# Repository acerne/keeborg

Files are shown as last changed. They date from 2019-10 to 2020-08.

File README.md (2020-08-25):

# Keeborg
*Oh look, another split keyboard*	

## Idea
Keeborg is a sandbox prototype inspired from split keyboards like ErgoDox, Iris, Sol2 and many others, that give your tumbs more to do besides spacebar mashing. Taking a level further with thoughts of rotary encoders, joysticks, trackballs and other input devices, rarely seen o na keyboard.

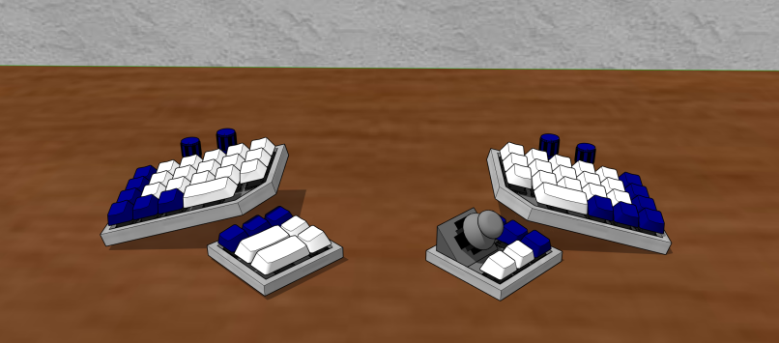
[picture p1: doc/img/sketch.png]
sketch
  

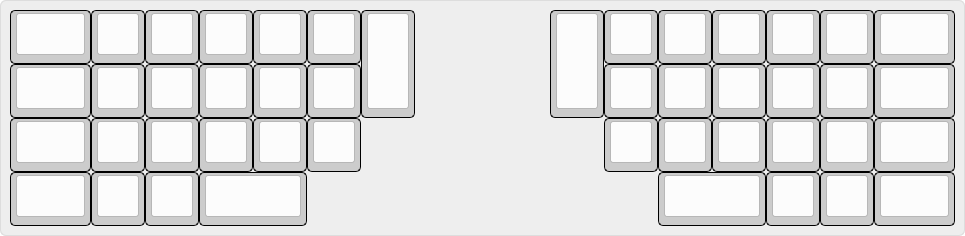
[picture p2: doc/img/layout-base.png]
layout
  

## Status
Designed a simple one-sided reversible PCB, made a fully functional thumb-less left-hand cluster. Had header connectors for some modular miny-pcb addons. After some testing decided it's not as expected and abandoned the project. 

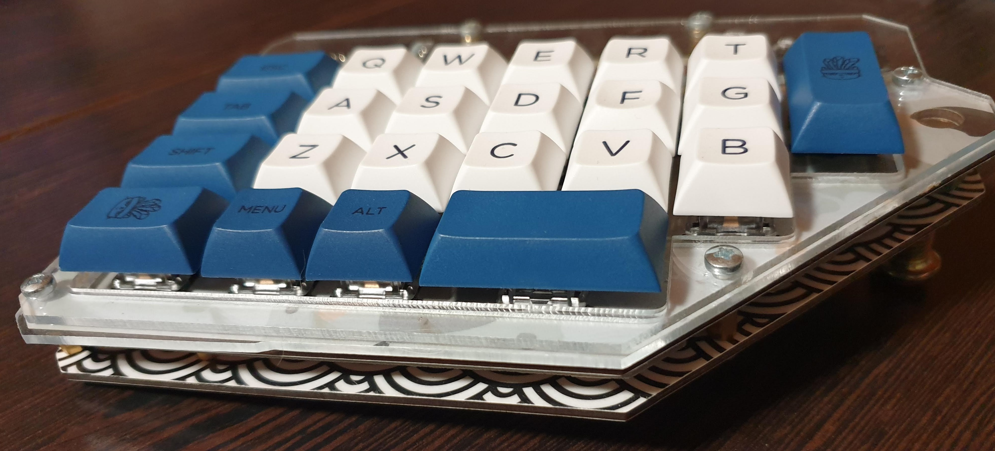
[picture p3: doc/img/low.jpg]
low
  

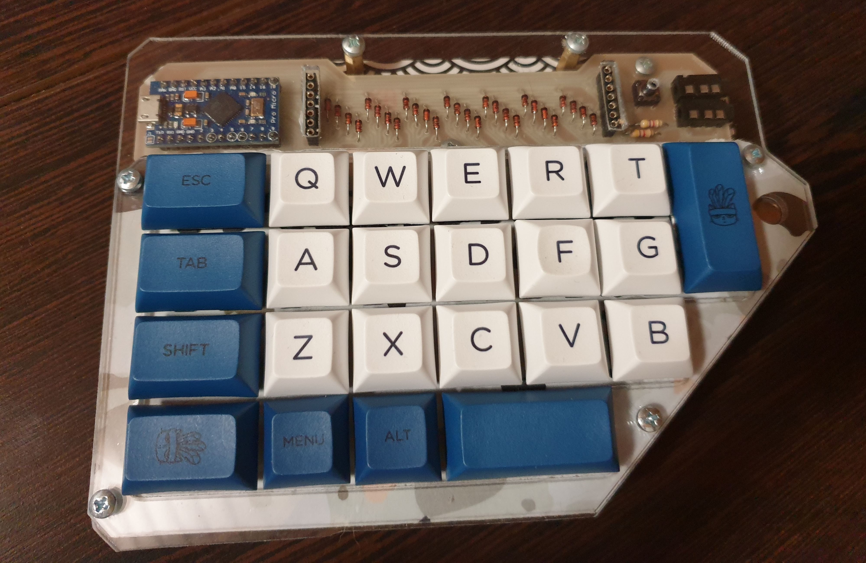
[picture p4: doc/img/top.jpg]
top


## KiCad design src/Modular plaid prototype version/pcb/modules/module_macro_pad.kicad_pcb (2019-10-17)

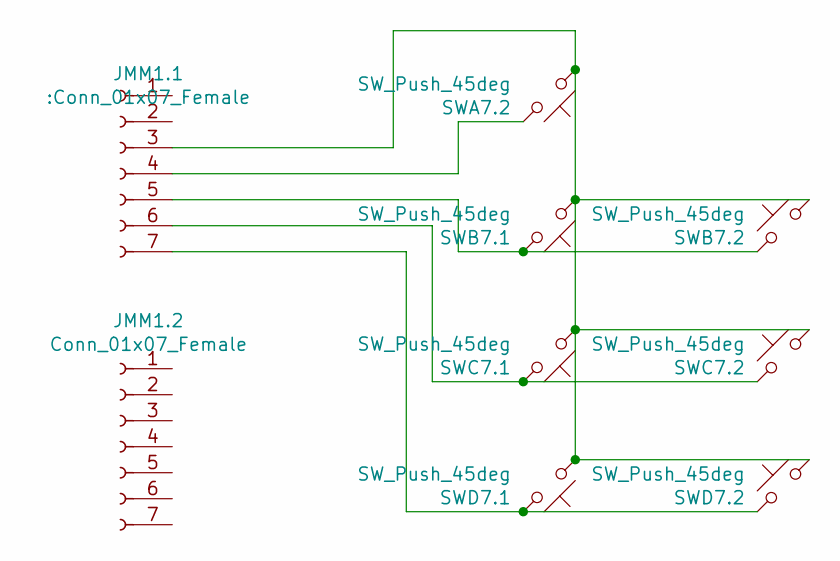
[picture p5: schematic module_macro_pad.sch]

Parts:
JMM1.1: :Conn_01x07_Female; PinHeader_1x07_P2.54mm_Vertical
JMM1.2: Conn_01x07_Female; PinHeader_1x07_P2.54mm_Vertical
SWA7.2: SW_Push_45deg; Hybrid_Plate_100H_Dual_hole-nosilk
SWB7.1, SWB7.2: SW_Push_45deg; Hybrid_Plate_100H_Dual_hole-nosilk
SWC7.1, SWC7.2: SW_Push_45deg; Hybrid_Plate_100H_Dual_hole-nosilk
SWD7.1, SWD7.2: SW_Push_45deg; Hybrid_Plate_100H_Dual_hole-nosilk

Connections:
unnamed: JMM1.1.3, SWA7.2.1, SWB7.1.1, SWB7.2.2, SWC7.1.1, SWC7.2.2, SWD7.1.1, SWD7.2.2
unnamed: JMM1.1.4, SWA7.2.2
unnamed: JMM1.1.5, SWB7.1.2, SWB7.2.1
unnamed: JMM1.1.6, SWC7.1.2, SWC7.2.1
unnamed: JMM1.1.7, SWD7.1.2, SWD7.2.1

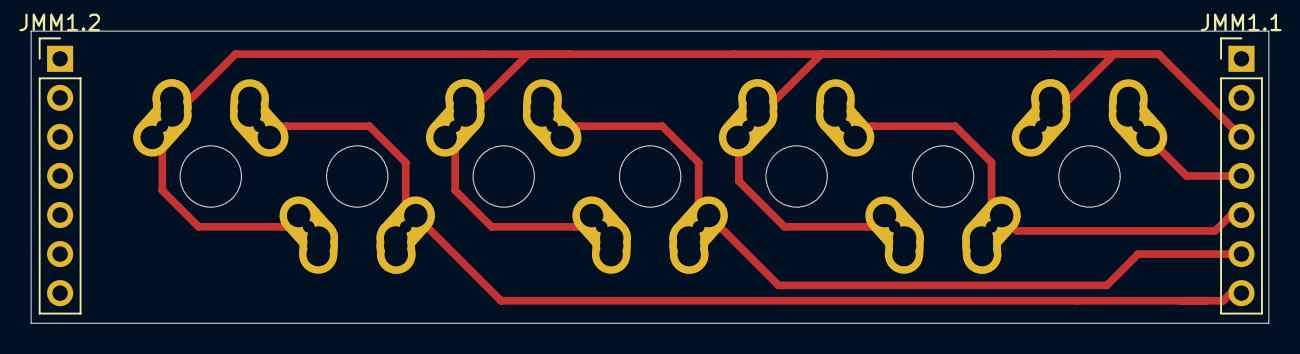
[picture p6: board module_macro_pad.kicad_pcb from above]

Board: 2 copper layers, 80.5 x 19.0 mm, 9 parts (0 on the bottom side), 5 nets.

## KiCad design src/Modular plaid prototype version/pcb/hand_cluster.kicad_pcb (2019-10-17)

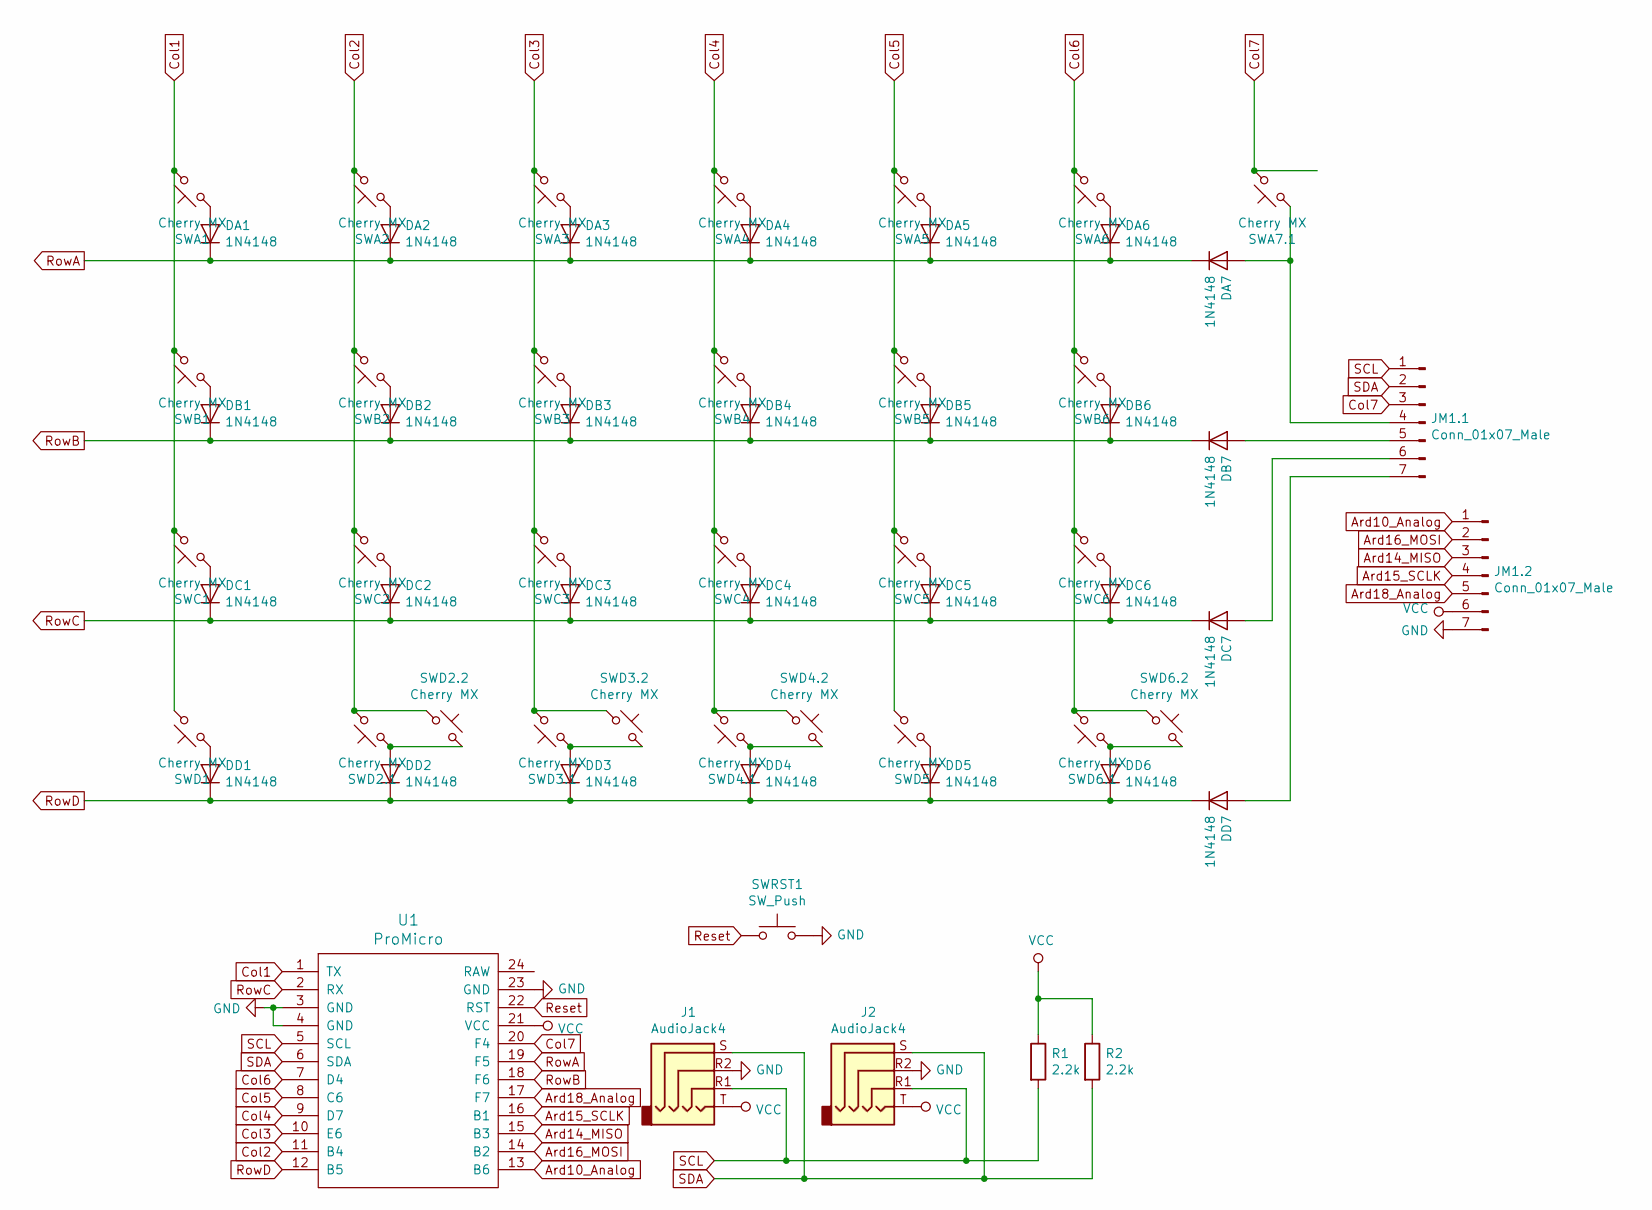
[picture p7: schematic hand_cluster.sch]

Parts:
DA1, DA2, DA3, DA4, DA5, DA6, DA7: 1N4148; D_DO-35_SOD27_P7.62mm_Horizontal
DB1, DB2, DB3, DB4, DB5, DB6, DB7: 1N4148; D_DO-35_SOD27_P7.62mm_Horizontal
DC1, DC2, DC3, DC4, DC5, DC6, DC7: 1N4148; D_DO-35_SOD27_P7.62mm_Horizontal
DD1, DD2, DD3, DD4, DD5, DD6, DD7: 1N4148; D_DO-35_SOD27_P7.62mm_Horizontal
J1, J2: AudioJack4; TRRS-PJ-320A-dual-labeled
JM1.1, JM1.2: Conn_01x07_Male; PinHeader_1x07_P2.54mm_Vertical
R1, R2: 2.2k; Resistor
SWA1: Cherry MX; Hybrid_Plate_150H_Dual_hole-nosilk
SWA2, SWA3, SWA4, SWA5, SWA6, SWA7.1: Cherry MX; Hybrid_Plate_100H_Dual_hole-nosilk
SWB1: Cherry MX; Hybrid_Plate_150H_Dual_hole-nosilk
SWB2, SWB3, SWB4, SWB5, SWB6: Cherry MX; Hybrid_Plate_100H_Dual_hole-nosilk
SWC1: Cherry MX; Hybrid_Plate_150H_Dual_hole-nosilk
SWC2, SWC3, SWC4, SWC5, SWC6: Cherry MX; Hybrid_Plate_100H_Dual_hole-nosilk
SWD1: Cherry MX; Hybrid_Plate_150H_Dual_hole-nosilk
SWD2.1, SWD2.2, SWD3.1, SWD3.2, SWD4.1, SWD4.2, SWD5, SWD6.1, SWD6.2: Cherry MX; Hybrid_Plate_100H_Dual_hole-nosilk
SWRST1: SW_Push; SW_PUSH_6mm
U1: ProMicro; ArduinoProMicro

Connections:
Ard10_Analog: JM1.2.1, U1.13 (B6)
Ard14_MISO: JM1.2.3, U1.15 (B3)
Ard15_SCLK: JM1.2.4, U1.16 (B1)
Ard16_MOSI: JM1.2.2, U1.14 (B2)
Ard18_Analog: JM1.2.5, U1.17 (F7)
Col1: SWA1.2, SWB1.2, SWC1.2, SWD1.2, U1.1 (TX)
Col2: SWA2.2, SWB2.2, SWC2.2, SWD2.1.2, SWD2.2.1, U1.11 (B4)
Col3: SWA3.2, SWB3.2, SWC3.2, SWD3.1.2, SWD3.2.1, U1.10 (E6)
Col4: SWA4.2, SWB4.2, SWC4.2, SWD4.1.2, SWD4.2.1, U1.9 (D7)
Col5: SWA5.2, SWB5.2, SWC5.2, SWD5.2, U1.8 (C6)
Col6: SWA6.2, SWB6.2, SWC6.2, SWD6.1.2, SWD6.2.1, U1.7 (D4)
Col7: JM1.1.3, SWA7.1.2, U1.20 (F4)
GND: J1.R2, J2.R2, JM1.2.7, SWRST1.2, U1.3 (GND), U1.4 (GND), U1.23 (GND)
unnamed: DA1.2 (A), SWA1.1
unnamed: DA2.2 (A), SWA2.1
unnamed: DA3.2 (A), SWA3.1
unnamed: DA4.2 (A), SWA4.1
unnamed: DA5.2 (A), SWA5.1
unnamed: DA6.2 (A), SWA6.1
unnamed: DA7.2 (A), JM1.1.4, SWA7.1.1
unnamed: DB1.2 (A), SWB1.1
unnamed: DB2.2 (A), SWB2.1
unnamed: DB3.2 (A), SWB3.1
unnamed: DB4.2 (A), SWB4.1
unnamed: DB5.2 (A), SWB5.1
unnamed: DB6.2 (A), SWB6.1
unnamed: DB7.2 (A), JM1.1.5
unnamed: DC1.2 (A), SWC1.1
unnamed: DC2.2 (A), SWC2.1
unnamed: DC3.2 (A), SWC3.1
unnamed: DC4.2 (A), SWC4.1
unnamed: DC5.2 (A), SWC5.1
unnamed: DC6.2 (A), SWC6.1
unnamed: DC7.2 (A), JM1.1.6
unnamed: DD1.2 (A), SWD1.1
unnamed: DD2.2 (A), SWD2.1.1, SWD2.2.2
unnamed: DD3.2 (A), SWD3.1.1, SWD3.2.2
unnamed: DD4.2 (A), SWD4.1.1, SWD4.2.2
unnamed: DD5.2 (A), SWD5.1
unnamed: DD6.2 (A), SWD6.1.1, SWD6.2.2
unnamed: DD7.2 (A), JM1.1.7
Reset: SWRST1.1, U1.22 (RST)
RowA: DA1.1 (K), DA2.1 (K), DA3.1 (K), DA4.1 (K), DA5.1 (K), DA6.1 (K), DA7.1 (K), U1.19 (F5)
RowB: DB1.1 (K), DB2.1 (K), DB3.1 (K), DB4.1 (K), DB5.1 (K), DB6.1 (K), DB7.1 (K), U1.18 (F6)
RowC: DC1.1 (K), DC2.1 (K), DC3.1 (K), DC4.1 (K), DC5.1 (K), DC6.1 (K), DC7.1 (K), U1.2 (RX)
RowD: DD1.1 (K), DD2.1 (K), DD3.1 (K), DD4.1 (K), DD5.1 (K), DD6.1 (K), DD7.1 (K), U1.12 (B5)
SCL: J1.R1, J2.R1, JM1.1.1, R1.2, U1.5 (SCL)
SDA: J1.S, J2.S, JM1.1.2, R2.2, U1.6 (SDA)
VCC: J1.T, J2.T, JM1.2.6, R1.1, R2.1, U1.21 (VCC)

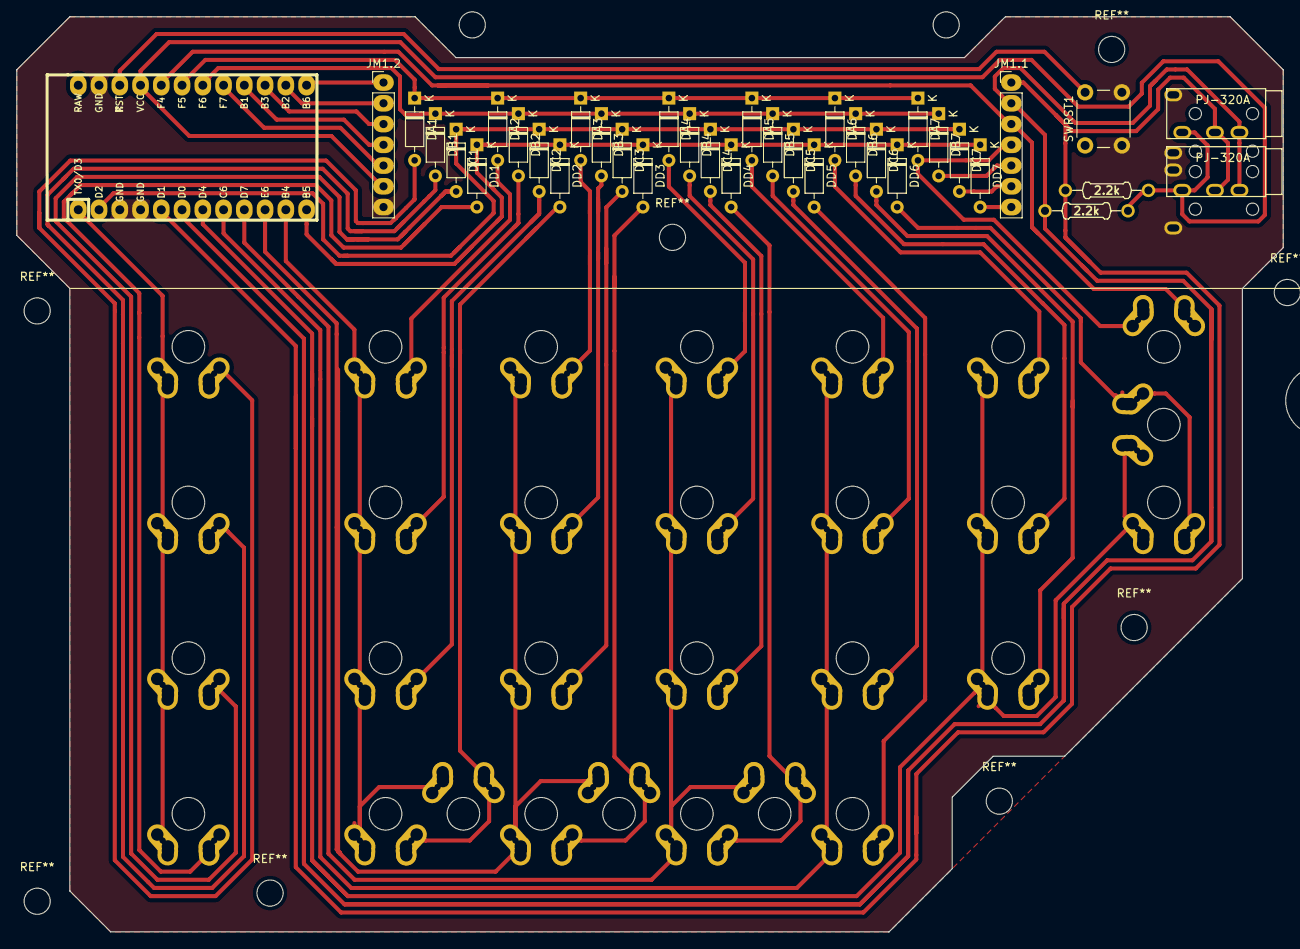
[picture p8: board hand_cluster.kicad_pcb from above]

Board: 2 copper layers, 155.0 x 112.0 mm, 65 parts (0 on the bottom side), 49 nets.

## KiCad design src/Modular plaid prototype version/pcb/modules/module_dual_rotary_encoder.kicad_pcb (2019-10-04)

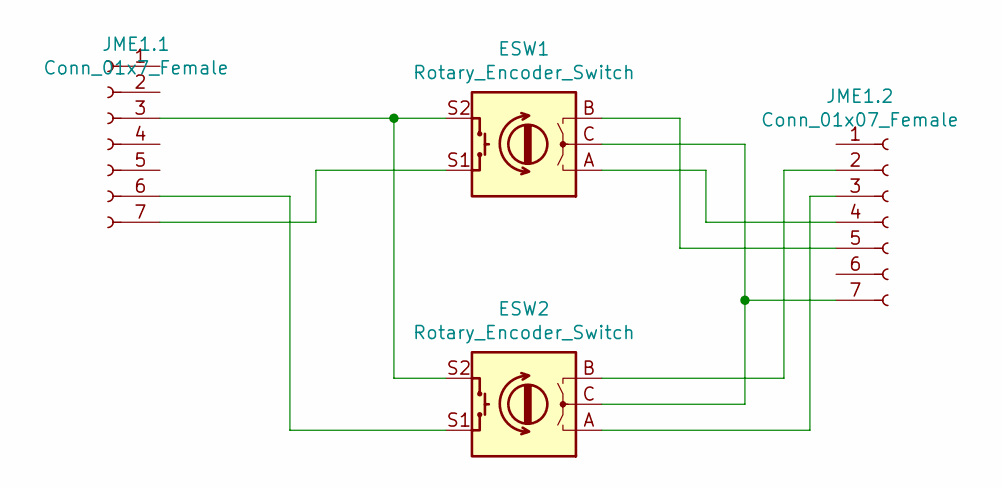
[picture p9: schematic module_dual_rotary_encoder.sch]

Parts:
ESW1, ESW2: Rotary_Encoder_Switch; RotaryEncoder_EC11
JME1.1: Conn_01x7_Female; PinHeader_1x07_P2.54mm_Vertical
JME1.2: Conn_01x07_Female; PinHeader_1x07_P2.54mm_Vertical

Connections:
unnamed: ESW1.A, JME1.2.4
unnamed: ESW1.B, JME1.2.5
unnamed: ESW1.C, ESW2.C, JME1.2.7
unnamed: ESW1.S1, JME1.1.7
unnamed: ESW1.S2, ESW2.S2, JME1.1.3
unnamed: ESW2.A, JME1.2.3
unnamed: ESW2.B, JME1.2.2
unnamed: ESW2.S1, JME1.1.6

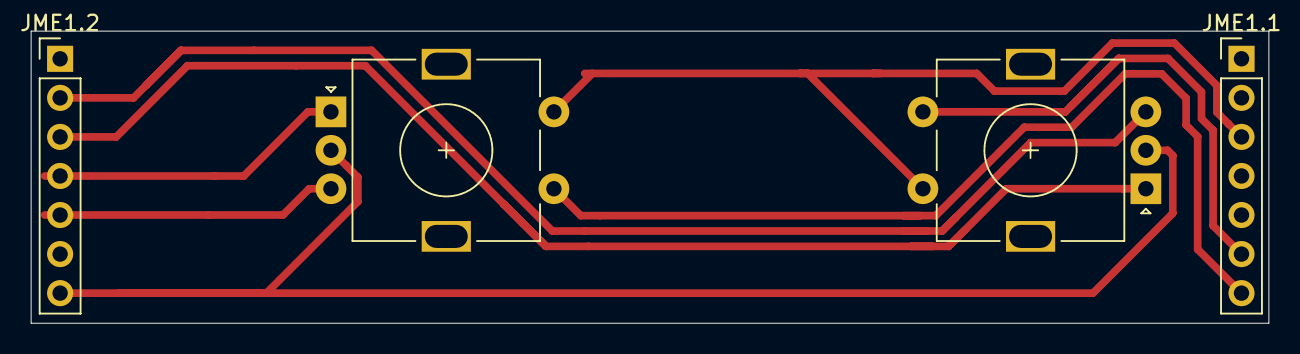
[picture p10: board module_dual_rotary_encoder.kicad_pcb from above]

Board: 2 copper layers, 80.5 x 19.0 mm, 4 parts (0 on the bottom side), 8 nets.

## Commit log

2019-09-21 Added the initial sandwich case design
2019-09-21 Updated the case design, merged everything into a single file
2019-09-25 Modified switchplate to square switch cutouts
2019-09-26 Started working on schematics
    [left.kicad_pcb, left.sch]
2019-09-27 Added excusions for unnecessary KiCad files
2019-09-27 Included another KiCad library as submodule
2019-09-27 Renamed pcb files, added two encoders to schematics
    [hand_cluster.kicad_pcb, hand_cluster.sch, left.sch]
2019-09-27 Deleted untracked pcb files
2019-09-27 Linked components with pcb footprints
    [hand_cluster.kicad_pcb, hand_cluster.sch]
2019-10-04 Designed the version of a plaid modular hand cluster
    [hand_cluster.kicad_pcb, hand_cluster.sch]
2019-10-04 Designed macropad and rotary encoder extension modules
    [module_dual_rotary_encoder.kicad_pcb, module_dual_rotary_encoder.sch, module_macro_pad.kicad_pcb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]
2019-10-17 Upadeted modular pcb project and moved them to modules folder
    [module_dual_rotary_encoder.kicad_pcb, module_dual_rotary_encoder.sch, module_macro_pad.kicad_pcb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]
2019-10-17 Modified the main pcb hand cluster to a near completed prototype design
    [hand_cluster.kicad_pcb, hand_cluster.sch]
2019-10-17 Added some customized footprints
2019-10-17 Moved files to different design folders
    [hand_cluster.kicad_pcb, hand_cluster.sch, module_dual_rotary_encoder.kicad_pcb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]
